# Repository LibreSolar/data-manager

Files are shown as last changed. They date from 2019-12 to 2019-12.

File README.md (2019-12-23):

# Data Manager for Libre Solar devices

 Prototype built, development and testing ongoing (especially firmware).

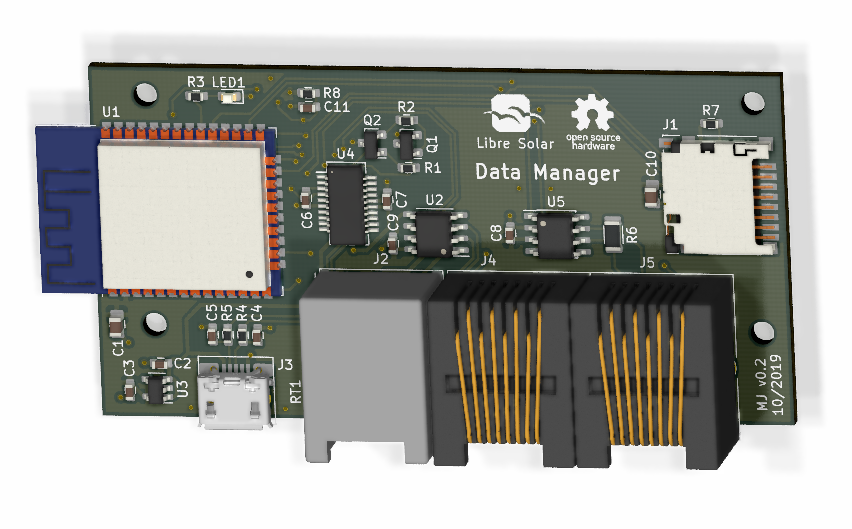
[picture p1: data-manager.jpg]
Data Manager PCB


Schematic: [PDF file](data-manager.pdf)

Firmware repository: [LibreSolar/data-manager-firmware](https://github.com/LibreSolar/data-manager-firmware)

## Features

- ESP32 WROOM board for WiFi and Bluetooth connection
- USB Micro-B power supply and debug serial
- microSD card slot
- LS.one interface (UART serial)
- LS.bus interface (CAN)
- Suitable housing: Hammond Mfg. 1591XXAFLBK

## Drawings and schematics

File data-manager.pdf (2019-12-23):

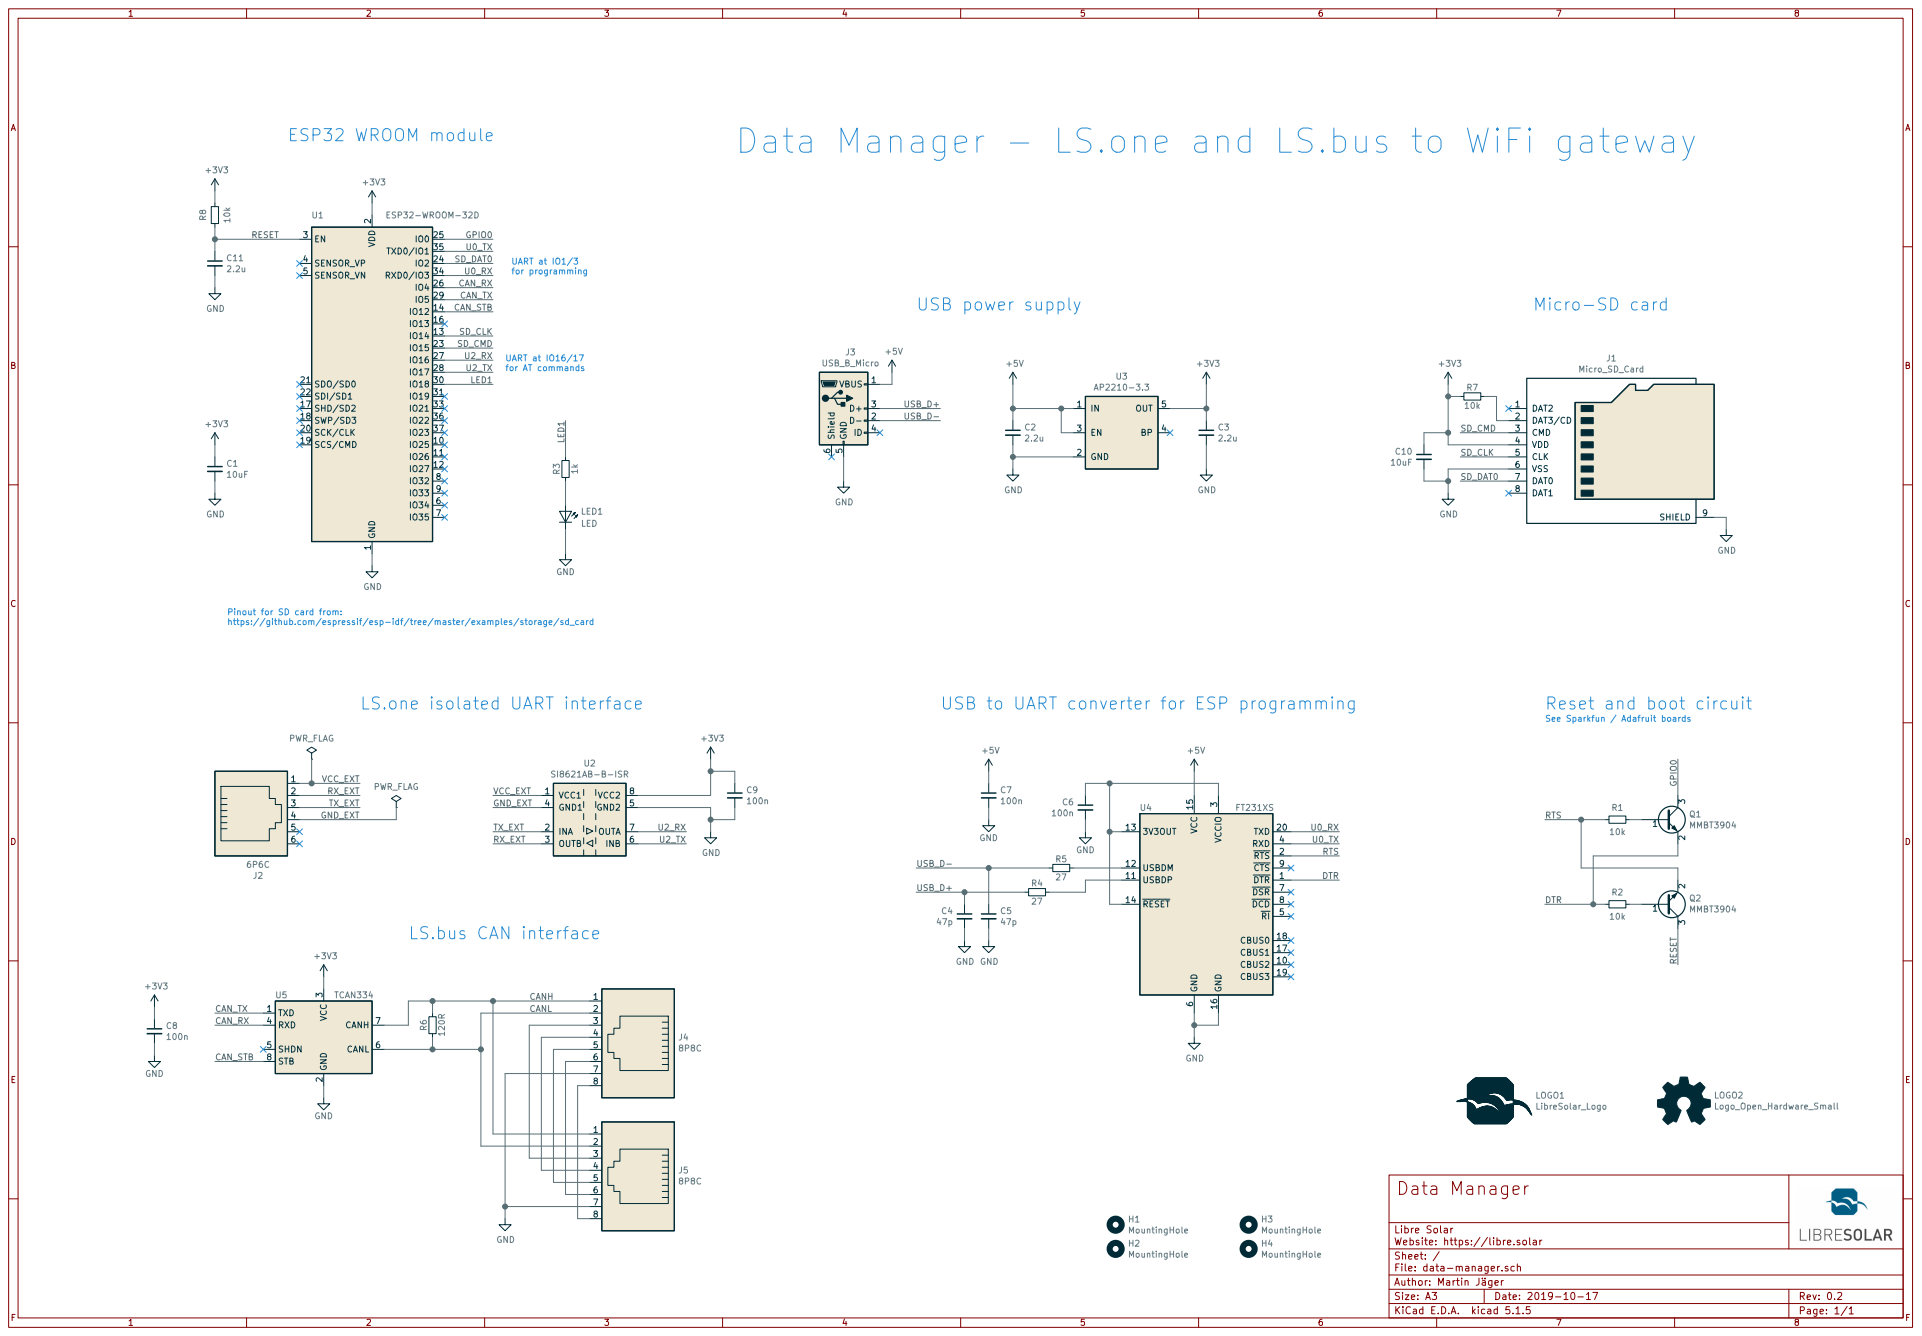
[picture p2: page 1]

Data Manager - LS.one and LS.bus to WiFi gateway

2 SCK/CLK 20 SDO/SD0 21 SDI/SD1 22

for AT commands UART at IO1/3
for programming

Pinout for SD card from: https://github.com/espressif/esp-idf/tree/master/examples/storage/sd_card UART at IO16/17

Reset and boot circuit

See Sparkfun / Adafruit boards

LS.bus CAN interface

3 RXD 4 SHDN 5 CANL 6 CANH 7 STB 8 U5 TCAN334 1

CANL 2

File: data-manager.sch Sheet: / Libre Solar Author: Martin Jäger
Website: https://libre.solar

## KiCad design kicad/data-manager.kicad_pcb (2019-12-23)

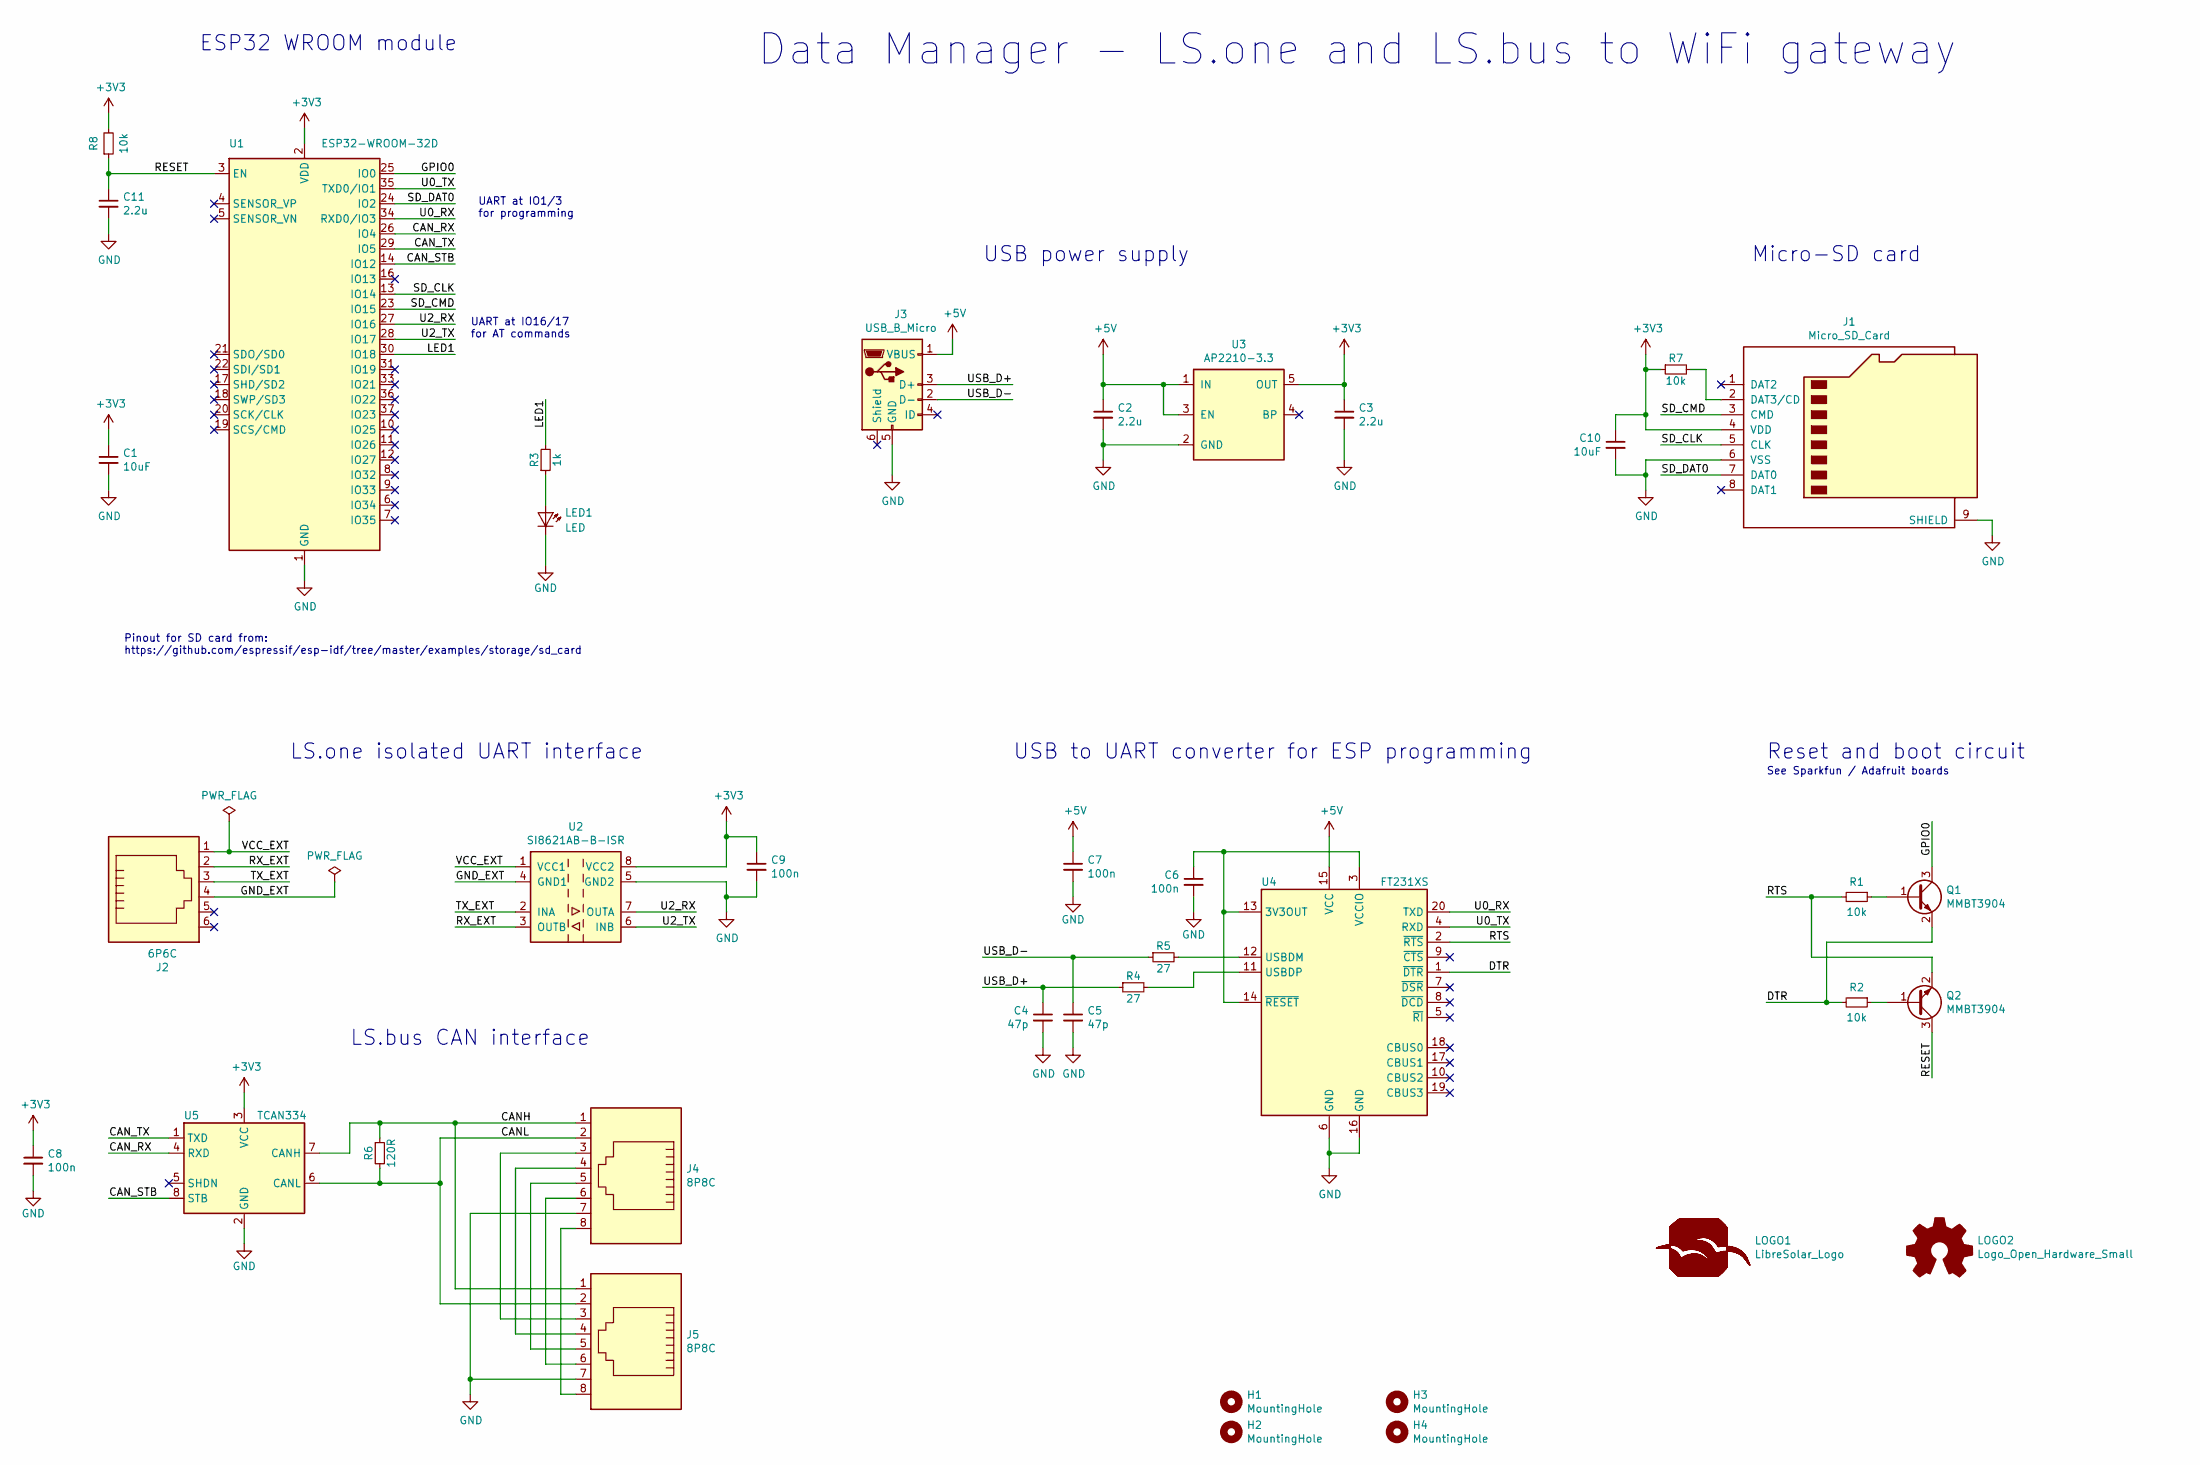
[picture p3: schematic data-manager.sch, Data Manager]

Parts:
C1, C10: 10uF; C_0805_2012; PartNumber GRM21BR61C106KE15L
C2, C3, C11: 2.2u; C_0603_1608
C4, C5: 47p; C_0603_1608
C6, C7, C8, C9: 100n; C_0603_1608
H1, H2, H3, H4: MountingHole; MountingHole_3mm
J1: Micro_SD_Card; microSD_HC_Hirose_DM3D-SF; PartNumber DM3D-SF
J2: 6P6C; RJ12_RJ25_6P6C_Amphenol_54601; PartNumber 54601-906WPLF
J3: USB_B_Micro; USB_Micro-B_10103594-0001LF
J4, J5: 8P8C; RJ45_8P8C
LED1: LED; LED_0603_1608Metric
LOGO1: LibreSolar_Logo; LIBRESOLAR_LOGO
LOGO2: Logo_Open_Hardware_Small; OSHW-Logo_5.7x6mm_SilkScreen
Q1, Q2: MMBT3904; SOT-23
R1, R2, R7, R8: 10k; R_0603_1608; PartNumber RC0603FR-0710KL
R3: 1k; R_0603_1608; PartNumber RC0603FR-071KL
R4, R5: 27; R_0603_1608; PartNumber RC0603FR-0727RL
R6: 120R; R_1206_3216; PartNumber RC1206FR-07120RL
U1: ESP32-WROOM-32D; ESP32-WROOM-32
U2: SI8621AB-B-ISR; SOIC-8_3.9x4.9mm_P1.27mm
U3: AP2210-3.3; SOT-23-5
U4: FT231XS; SSOP-20_3.9x8.7mm_P0.635mm
U5: TCAN334; SOIC-8_3.9x4.9mm_Pitch1.27mm

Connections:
+3V3: C1.1, C3.1, C8.1, C9.1, C10.1, J1.4 (VDD), R7.1, R8.2, U1.2 (VDD), U2.8 (VCC2), U3.5 (OUT), U5.3 (VCC)
+5V: C2.1, C7.1, J3.1 (VBUS), U3.1 (IN), U3.3 (EN), U4.15 (VCC)
/CANH: J4.1, J5.1, R6.1, U5.7 (CANH)
/CANL: J4.2, J5.2, R6.2, U5.6 (CANL)
/CAN_RX: U1.26 (IO4), U5.4 (RXD)
/CAN_STB: U1.14 (IO12), U5.8 (STB)
/CAN_TX: U1.29 (IO5), U5.1 (TXD)
/DTR: Q1.2 (E), R2.2, U4.1 (~DTR)
/GND_EXT: J2.4, U2.4 (GND1)
/GPIO0: Q1.3 (C), U1.25 (IO0)
/LED1: R3.2, U1.30 (IO18)
/RESET: C11.1, Q2.3 (C), R8.1, U1.3 (EN)
/RTS: Q2.2 (E), R1.2, U4.2 (~RTS)
/RX_EXT: J2.2, U2.3 (OUTB)
/SD_CLK: J1.5 (CLK), U1.13 (IO14)
/SD_CMD: J1.3 (CMD), U1.23 (IO15)
/SD_DAT0: J1.7 (DAT0), U1.24 (IO2)
/TX_EXT: J2.3, U2.2 (INA)
/U0_RX: U1.34 (RXD0/IO3), U4.20 (TXD)
/U0_TX: U1.35 (TXD0/IO1), U4.4 (RXD)
/U2_RX: U1.27 (IO16), U2.7 (OUTA)
/U2_TX: U1.28 (IO17), U2.6 (INB)
/USB_D+: C4.1, J3.3 (D+), R4.1
/USB_D-: C5.1, J3.2 (D-), R5.1
/VCC_EXT: J2.1, U2.1 (VCC1)
GND: C1.2, C2.2, C3.2, C4.2, C5.2, C6.2, C7.2, C8.2, C9.2, C10.2, C11.2, J1.6 (VSS), J1.9 (SHIELD), J3.5 (GND), J4.7, J5.7, LED1.1 (K), U1.1 (GND), U1.15 (GND), U1.38 (GND), U2.5 (GND2), U3.2 (GND), U4.6 (GND), U4.16 (GND), U5.2 (GND)
unnamed: C6.1, U4.3 (VCCIO), U4.13 (3V3OUT), U4.14 (~RESET)
unnamed: J1.2 (DAT3/CD), R7.2
unnamed: J4.3, J5.3
unnamed: J4.4, J5.4
unnamed: J4.5, J5.5
unnamed: J4.6, J5.6
unnamed: J4.8, J5.8
unnamed: LED1.2 (A), R3.1
unnamed: Q1.1 (B), R1.1
unnamed: Q2.1 (B), R2.1
unnamed: R4.2, U4.11 (USBDP)
unnamed: R5.2, U4.12 (USBDM)

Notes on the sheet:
UART at IO1/3 for programming
UART at IO16/17 for AT commands
See Sparkfun / Adafruit boards
Reset and boot circuit
ESP32 WROOM module
Pinout for SD card from: https://github.com/espressif/esp-idf/tree/master/examples/storage/sd_card
USB power supply
LS.bus CAN interface
Micro-SD card
LS.one isolated UART interface
USB to UART converter for ESP programming
Data Manager - LS.one and LS.bus to WiFi gateway

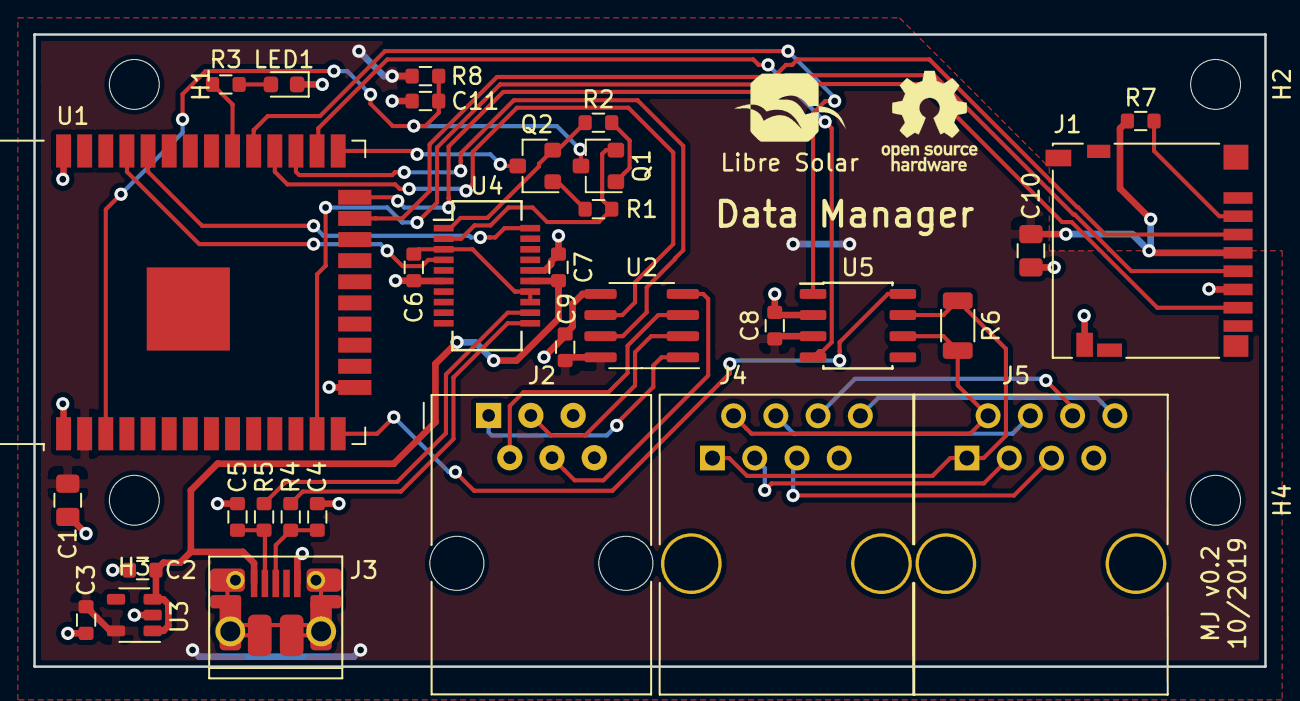
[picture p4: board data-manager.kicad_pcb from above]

Board: 2 copper layers, 74.0 x 38.0 mm, 38 parts (0 on the bottom side), 38 nets.

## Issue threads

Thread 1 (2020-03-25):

Wrong SD card pinout

martinjaeger, 2020-03-25:
In contrast to most other peripherals, the SD card pins *must* have the exact pinout as specified [here](https://docs.espressif.com/projects/esp-idf/en/latest/esp32/api-reference/peripherals/sdmmc_host.html). This needs to be fixed for next revision.

guigur, 2022-04-22:
hello,
I recently joined the OwnTech team and they told me to check out your stuff.
We were in the need of a bridge between the CAN bus WiFi and your project checks all the boxes.
So I took the liberty to rework a little bit the schematic and the board with the advice you have given through the issues.

I haven't moved the connectors nor the esp. This is generating some DRC errors due to courtyards overlapping but it's not a big deal.

Concerning the pinout, I tested the circuit on a breadboard and an Huzzah32. I can read and write on the SD with only one pull-up on the MISO pin but based on your recommendations, I added on every SD IO a 10k pull-up.

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

Can you tell me if you have any changes requests? And if everything is ok, I will submit a PR.

best regards.

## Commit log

2019-10-17 Initial commit of v0.1 board
    [DataManager.kicad_pcb, DataManager.sch]
2019-12-23 Board v0.2: Errors fixed
    - Pull-up resistor on reset pin
    - LS.one (serial) pinout fixed (reversed)
    - Isolator U2 RX/TX pinout fixed
    - PCB mounting hole diameter enlarged to 3 mm
    [DataManager.kicad_pcb, DataManager.sch]
2019-12-23 Files renamed and PDF schematic added
    [data-manager.kicad_pcb, data-manager.sch]
